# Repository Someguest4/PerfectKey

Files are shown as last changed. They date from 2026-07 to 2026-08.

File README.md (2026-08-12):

# Perfectionist Keyboard
A project following the [HackClub KEEB project tutorial](https://keeb.hackclub.com/docs), making a custom mechanical keyboard from scratch.

I have always been a perfectionist and I often find myself following the lines between the keys on my keyboard instead of doing my homework so I decided to make a keyboard with perfectly aligned keys.

## What it is
An ortholinear TKL keyboard, designed from scratch in KiCad. All modifier keys are 2u, spacebar is 7u, board is 380x147fmm with a strip for the Pico, switches are on the normal 19.05mm grid, USB-C with a cutout in the case, just one stabilizer for the spacebar, because the footprints wouldn't fit directly above each other and it's not like the 2u keys will wobble enough to need a stabilizer :|

## Repo structure
- `kicad/` - schematic and PCB layout, Gerbers, drill files
- `case/` - case and plate files
- `photos/` - build photos for journal
- `firmware/` compiled ready to flash firmware
## Build log

**2026-07-11 - Schematic:**
Read through the guide and designed the schematic. Switch matrix, diodes so it doesn't ghost, stabs, wired it all to the Pico.

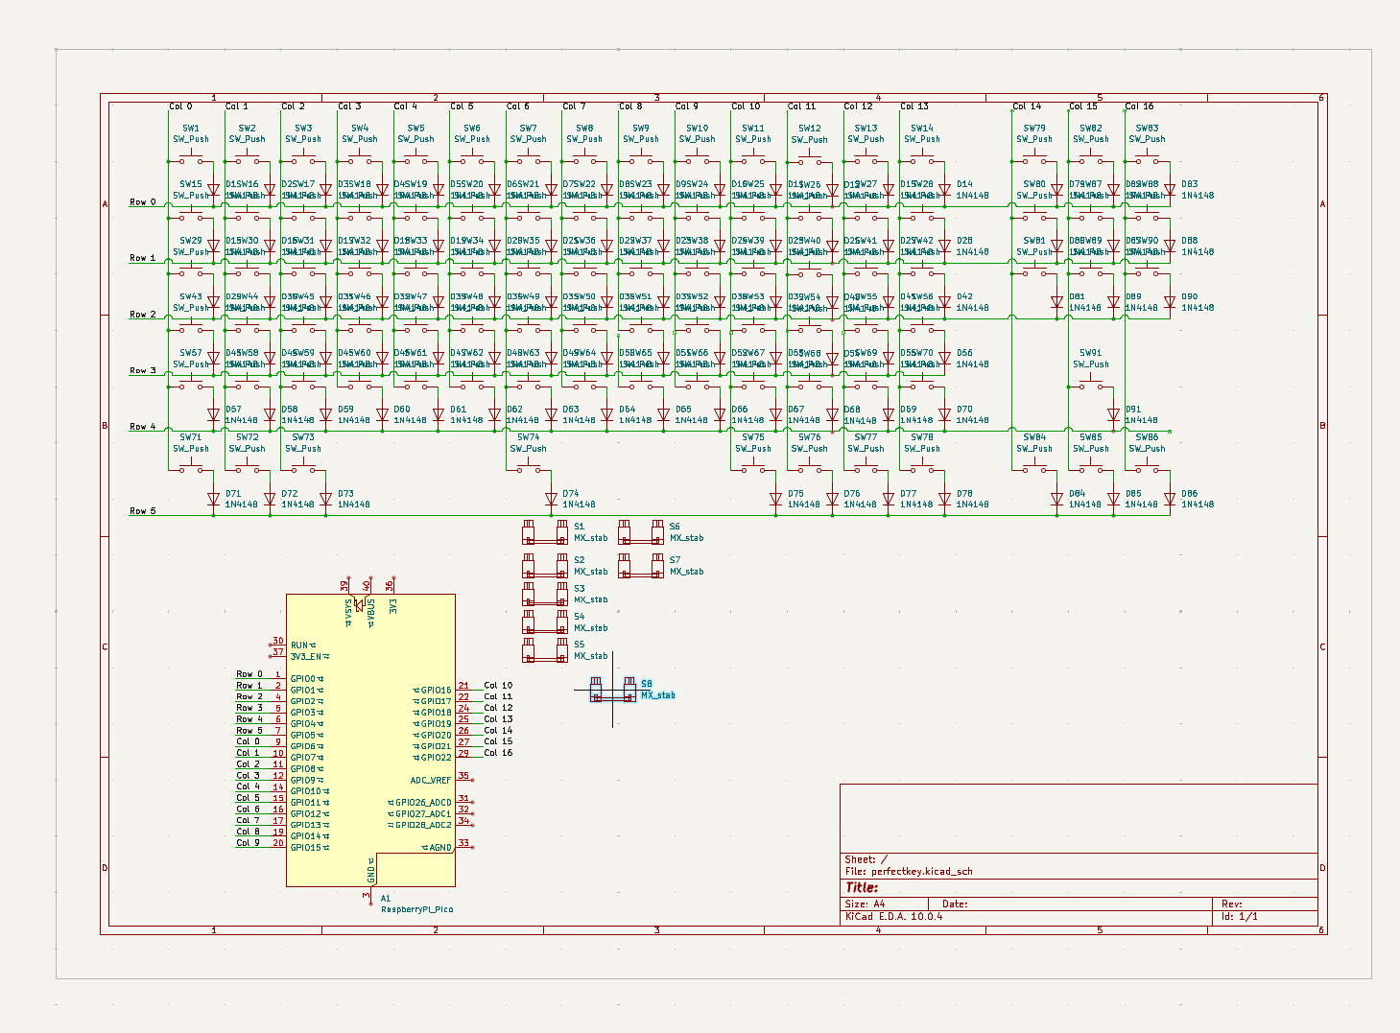
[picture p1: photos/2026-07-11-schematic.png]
Schematic


**2026-07-14 - Started placing switches:**

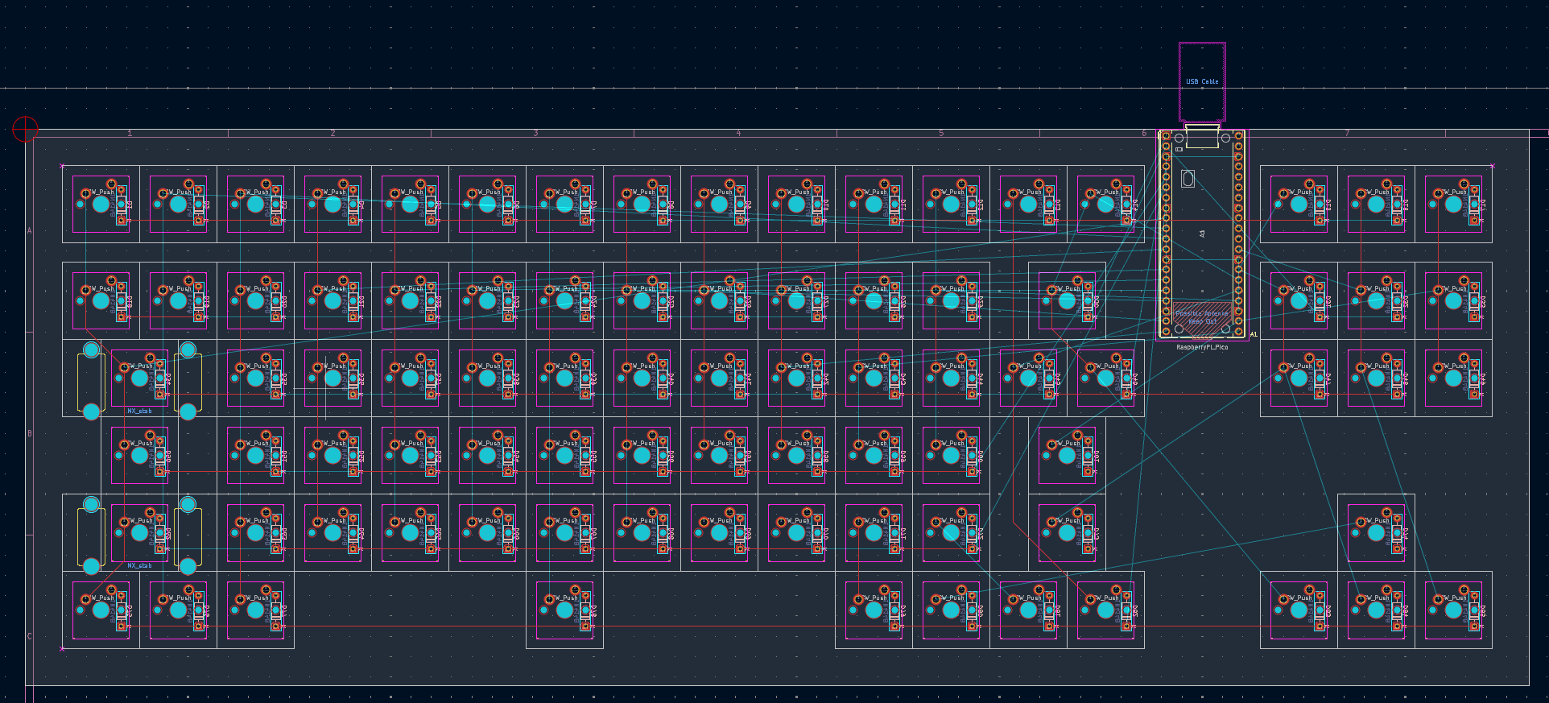
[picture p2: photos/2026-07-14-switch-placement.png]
Switch placement


**2026-07-15 - Switches were completely wrong:**
Got the kicad-kbplacer plugin to place the keys instead and made the layout in KLE.

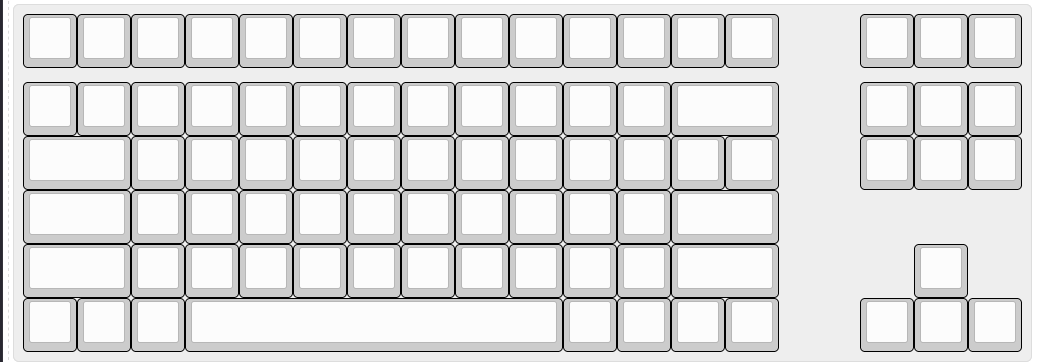
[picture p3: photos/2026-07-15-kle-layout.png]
KLE layout


**2026-07-16 - Numbering everything:**
Had to number all the keys in KLE because kbplacer wouldn't place them correctly without an index, renamed all the rows and columns so it would recognize them.
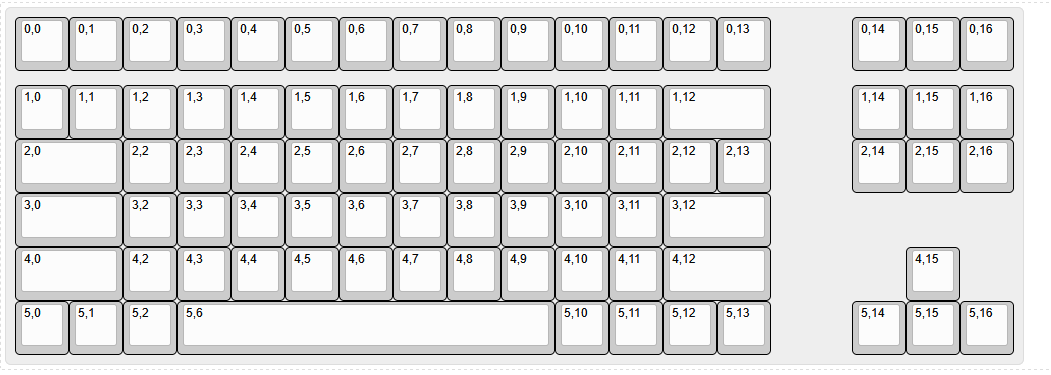
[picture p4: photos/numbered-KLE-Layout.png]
KLE layout


**2026-07-17 - Routing:**
Routing cables and rerouting until they fit.

**2026-07-18 - Diodes, PCB finished:**
Kbplacer put the diodes inside the courtyards of the switches and the cables were so tight around them. I couldn't move them, so I had to reroute first. PCB finished after that.

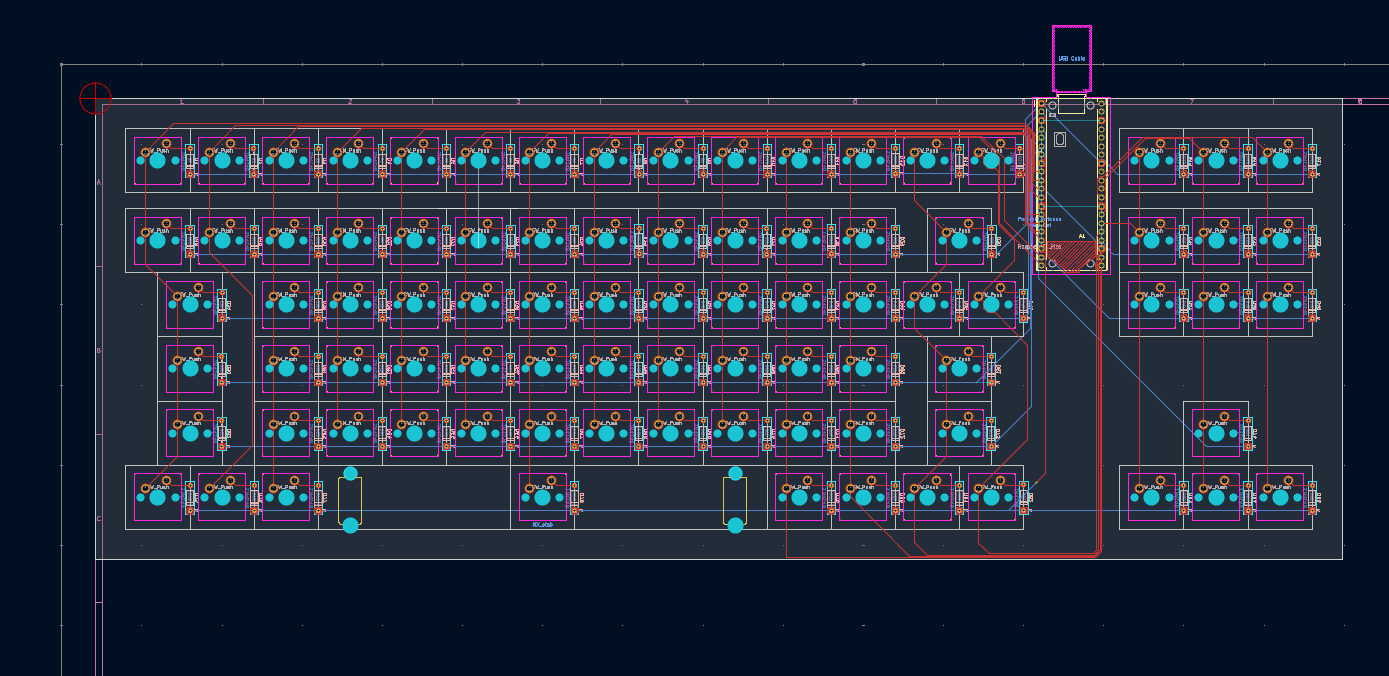
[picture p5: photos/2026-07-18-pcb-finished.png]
Finished PCB


**2026-07-22 - Starting the case:**
Started designing the case, rage quit because of Onshape (can't expect much from browser based software), switched to Fusion.

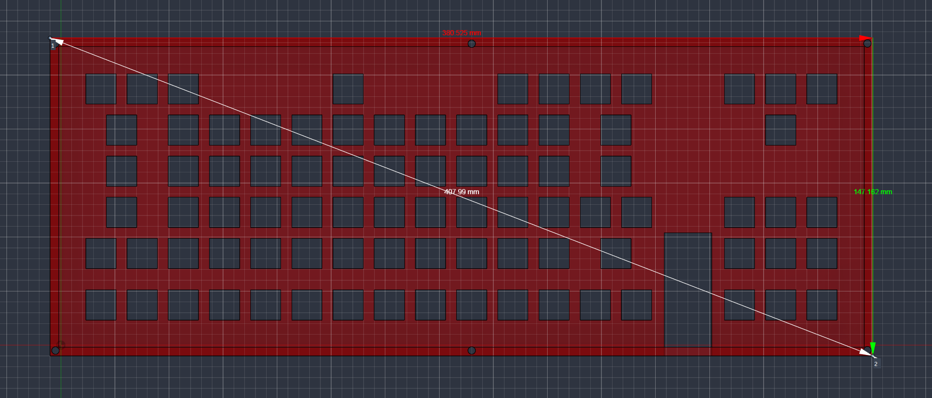
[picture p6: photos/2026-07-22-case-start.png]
Case start


**2026-07-23 - Case, mostly finished:**
Did most of the case but no space for screw holes.

**2026-07-24 - Case finished:**
Made the case bigger so the holes fit and made the top plate removable.

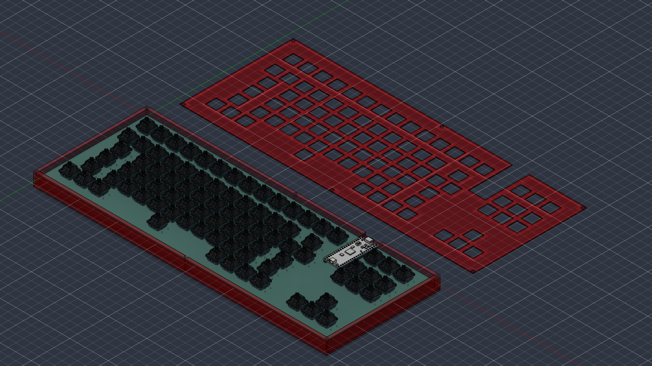
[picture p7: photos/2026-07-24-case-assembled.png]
Case assembled

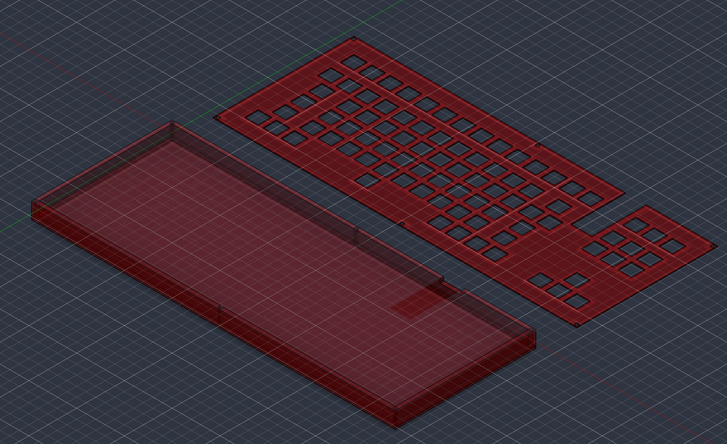
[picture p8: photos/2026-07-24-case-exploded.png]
Case exploded view


## Firmware
I went with QMK since I used it for my hackpad. All handwired since it's a custom layout. Compiles clean, just waiting on the actual hardware to test.

## Status
Everything done, hoping and waiting for approval

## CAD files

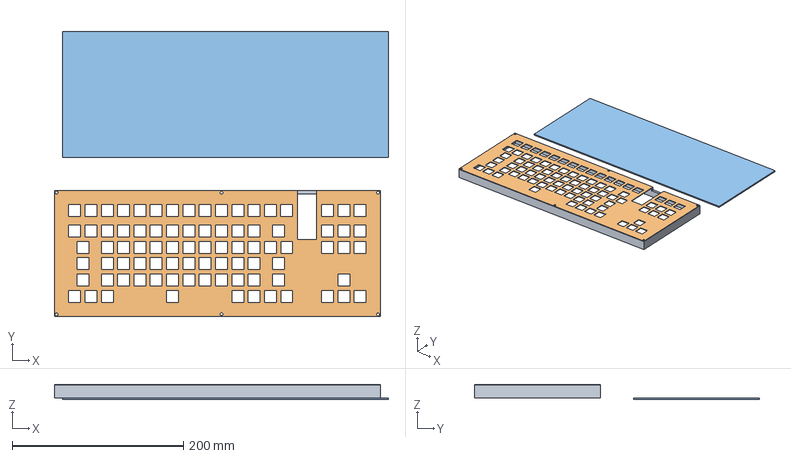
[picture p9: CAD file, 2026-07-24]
case/perfectkey_case.step
390.1 x 332.9 x 18.0 mm

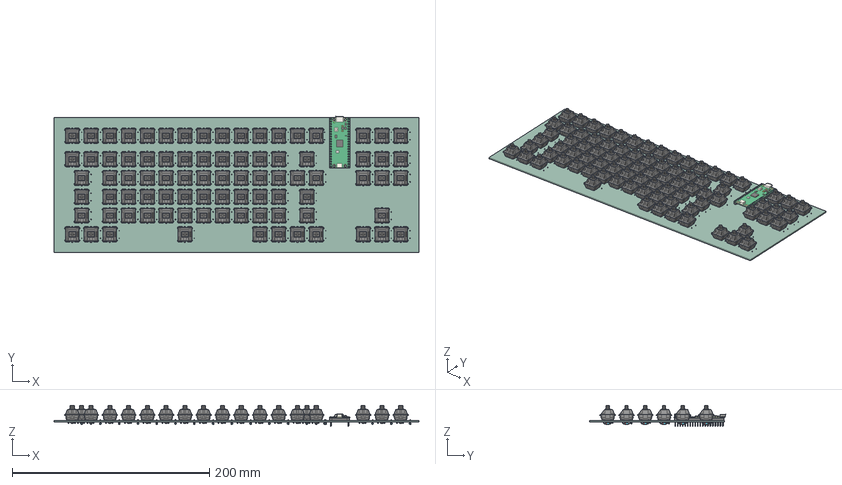
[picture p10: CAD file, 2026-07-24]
kicad/perfectkey_pcb.step
370.5 x 138.2 x 21.6 mm
MX1A-11NN x 85
RaspberryPi_Pico_H_Module_KiCad
RaspberryPi_Pico_Header_DIP-40_H2.54mm_KiCad
D_DO-35_SOD27_P7.62mm_Horizontal x 85
perfectkey_PCB

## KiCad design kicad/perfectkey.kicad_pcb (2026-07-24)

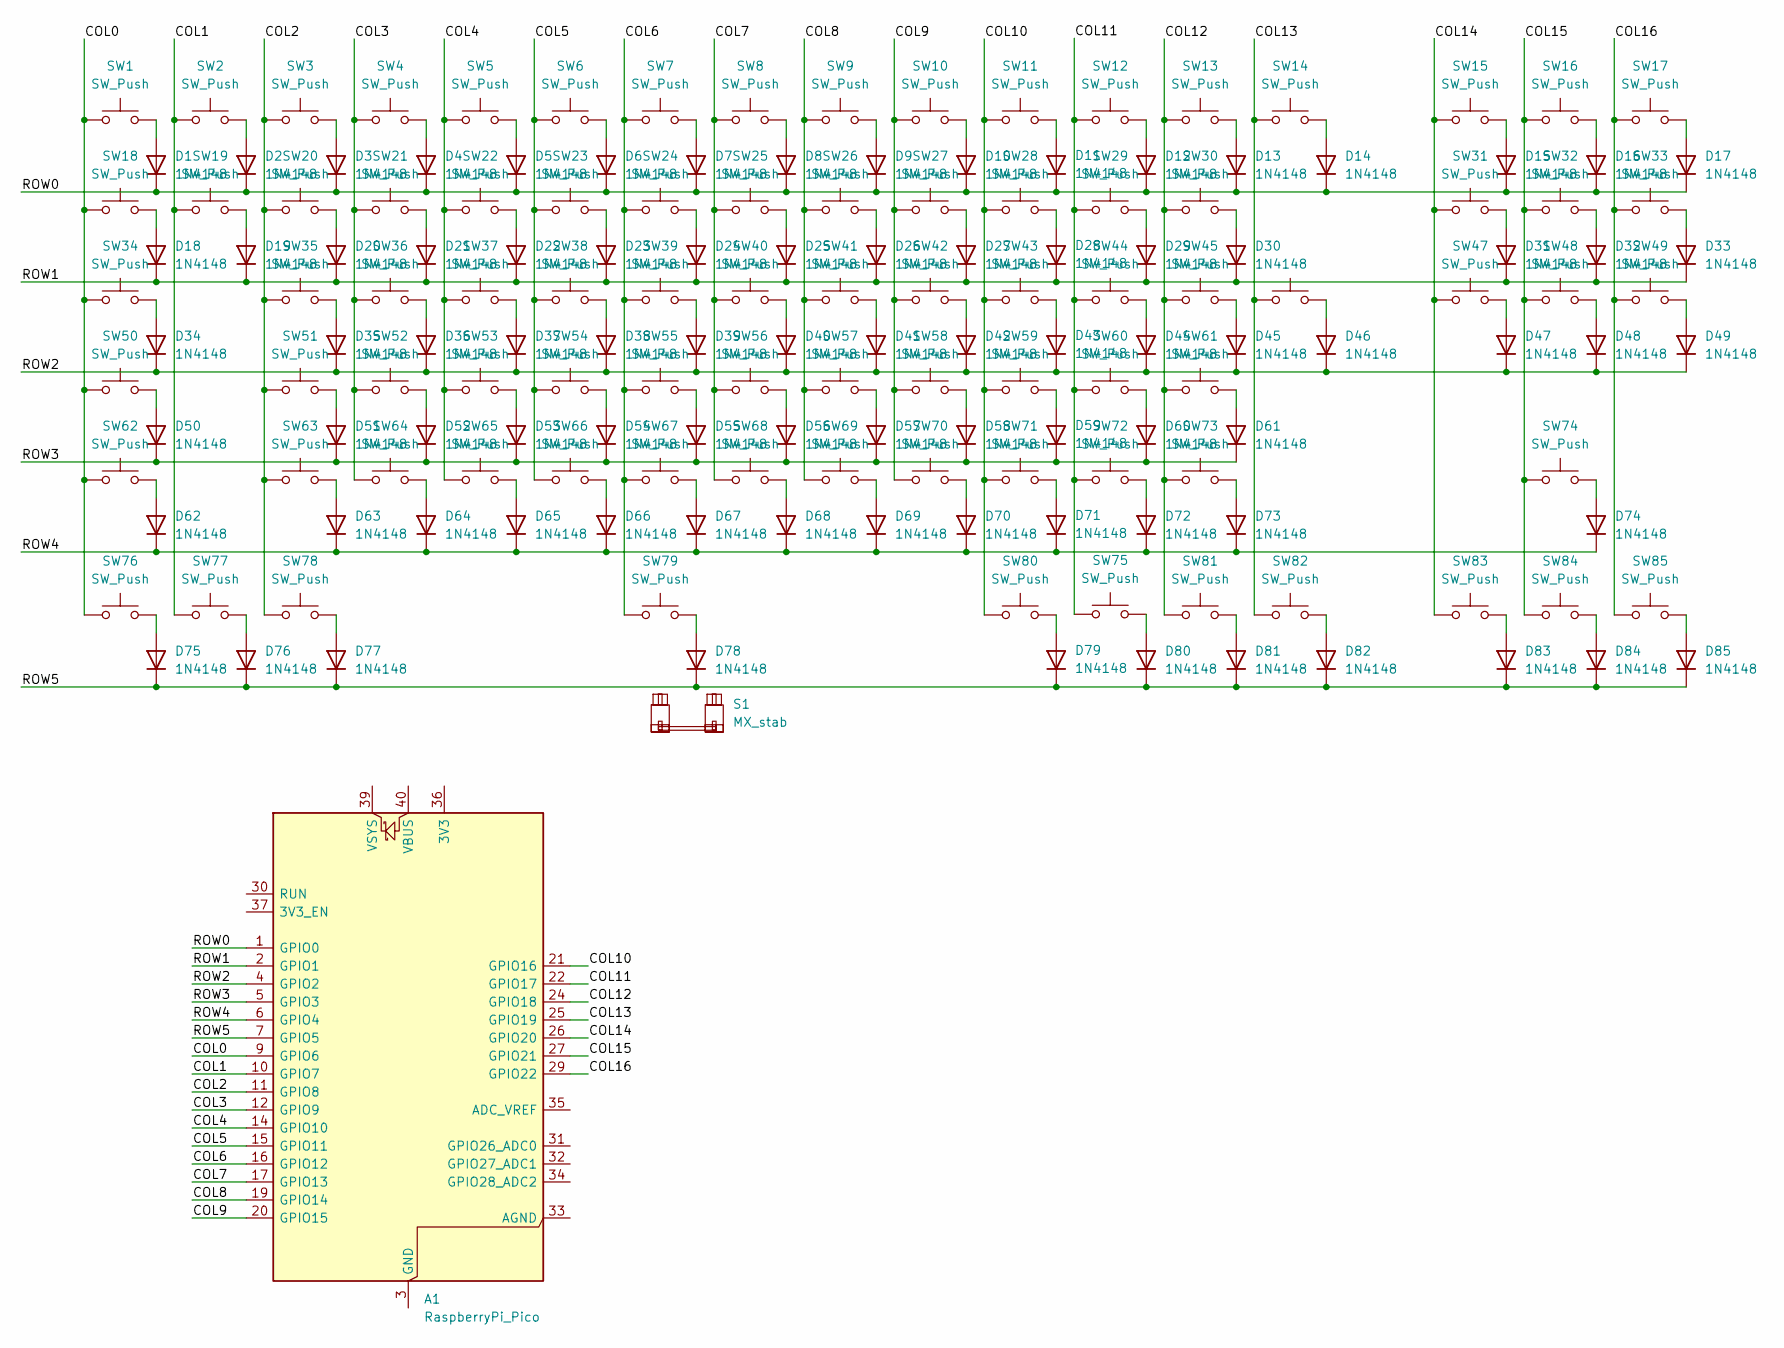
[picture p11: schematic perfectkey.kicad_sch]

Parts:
A1: RaspberryPi_Pico; RaspberryPi_Pico_Common_THT
D1, D2, D3, D4, D5, D6, D7, D8, D9, D10, D11, D12, D13, D14, D15, D16, D17, D18, D19, D20, D21, D22, D23, D24, D25, D26, D27, D28, D29, D30, D31, D32, D33, D34, D35, D36, D37, D38, D39, D40, D41, D42, D43, D44, D45, D46, D47, D48, D49, D50, D51, D52, D53, D54, D55, D56, D57, D58, D59, D60, D61, D62, D63, D64, D65, D66, D67, D68, D69, D70, D71, D72, D73, D74, D75, D76, D77, D78, D79, D80, D81, D82, D83, D84, D85: 1N4148; D_DO-35_SOD27_P7.62mm_Horizontal
S1: MX_stab; STAB_MX_7u
SW1, SW2, SW3, SW4, SW5, SW6, SW7, SW8, SW9, SW10, SW11, SW12, SW13, SW14, SW15, SW16, SW17, SW18, SW19, SW20, SW21, SW22, SW23, SW24, SW25, SW26, SW27, SW28, SW29, SW30, SW31, SW32, SW33, SW34, SW35, SW36, SW37, SW38, SW39, SW40, SW41, SW42, SW43, SW44, SW45, SW46, SW47, SW48, SW49, SW50, SW51, SW52, SW53, SW54, SW55, SW56, SW57, SW58, SW59, SW60, SW61, SW62, SW63, SW64, SW65, SW66, SW67, SW68, SW69, SW70, SW71, SW72, SW73, SW74, SW75, SW76, SW77, SW78, SW79, SW80, SW81, SW82, SW83, SW84, SW85: SW_Push; SW_MX_1u

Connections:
/COL0: A1.9 (GPIO6), SW1.1, SW18.1, SW34.1, SW50.1, SW62.1, SW76.1
/COL1: A1.10 (GPIO7), SW2.1, SW19.1, SW77.1
/COL2: A1.11 (GPIO8), SW3.1, SW20.1, SW35.1, SW51.1, SW63.1, SW78.1
/COL3: A1.12 (GPIO9), SW4.1, SW21.1, SW36.1, SW52.1, SW64.1
/COL4: A1.14 (GPIO10), SW5.1, SW22.1, SW37.1, SW53.1, SW65.1
/COL5: A1.15 (GPIO11), SW6.1, SW23.1, SW38.1, SW54.1, SW66.1
/COL6: A1.16 (GPIO12), SW7.1, SW24.1, SW39.1, SW55.1, SW67.1, SW79.1
/COL7: A1.17 (GPIO13), SW8.1, SW25.1, SW40.1, SW56.1, SW68.1
/COL8: A1.19 (GPIO14), SW9.1, SW26.1, SW41.1, SW57.1, SW69.1
/COL9: A1.20 (GPIO15), SW10.1, SW27.1, SW42.1, SW58.1, SW70.1
/COL10: A1.21 (GPIO16), SW11.1, SW28.1, SW43.1, SW59.1, SW71.1, SW80.1
/COL11: A1.22 (GPIO17), SW12.1, SW29.1, SW44.1, SW60.1, SW72.1, SW75.1
/COL12: A1.24 (GPIO18), SW13.1, SW30.1, SW45.1, SW61.1, SW73.1, SW81.1
/COL13: A1.25 (GPIO19), SW14.1, SW46.1, SW82.1
/COL14: A1.26 (GPIO20), SW15.1, SW31.1, SW47.1, SW83.1
/COL15: A1.27 (GPIO21), SW16.1, SW32.1, SW48.1, SW74.1, SW84.1
/COL16: A1.29 (GPIO22), SW17.1, SW33.1, SW49.1, SW85.1
/ROW0: A1.1 (GPIO0), D1.1 (K), D2.1 (K), D3.1 (K), D4.1 (K), D5.1 (K), D6.1 (K), D7.1 (K), D8.1 (K), D9.1 (K), D10.1 (K), D11.1 (K), D12.1 (K), D13.1 (K), D14.1 (K), D15.1 (K), D16.1 (K), D17.1 (K)
/ROW1: A1.2 (GPIO1), D18.1 (K), D19.1 (K), D20.1 (K), D21.1 (K), D22.1 (K), D23.1 (K), D24.1 (K), D25.1 (K), D26.1 (K), D27.1 (K), D28.1 (K), D29.1 (K), D30.1 (K), D31.1 (K), D32.1 (K), D33.1 (K)
/ROW2: A1.4 (GPIO2), D34.1 (K), D35.1 (K), D36.1 (K), D37.1 (K), D38.1 (K), D39.1 (K), D40.1 (K), D41.1 (K), D42.1 (K), D43.1 (K), D44.1 (K), D45.1 (K), D46.1 (K), D47.1 (K), D48.1 (K), D49.1 (K)
/ROW3: A1.5 (GPIO3), D50.1 (K), D51.1 (K), D52.1 (K), D53.1 (K), D54.1 (K), D55.1 (K), D56.1 (K), D57.1 (K), D58.1 (K), D59.1 (K), D60.1 (K), D61.1 (K)
/ROW4: A1.6 (GPIO4), D62.1 (K), D63.1 (K), D64.1 (K), D65.1 (K), D66.1 (K), D67.1 (K), D68.1 (K), D69.1 (K), D70.1 (K), D71.1 (K), D72.1 (K), D73.1 (K), D74.1 (K)
/ROW5: A1.7 (GPIO5), D75.1 (K), D76.1 (K), D77.1 (K), D78.1 (K), D79.1 (K), D80.1 (K), D81.1 (K), D82.1 (K), D83.1 (K), D84.1 (K), D85.1 (K)
unnamed: A1.3 (GND), A1.8 (GND), A1.13 (GND), A1.18 (GND), A1.23 (GND), A1.28 (GND), A1.38 (GND)
unnamed: D1.2 (A), SW1.2
unnamed: D2.2 (A), SW2.2
unnamed: D3.2 (A), SW3.2
unnamed: D4.2 (A), SW4.2
unnamed: D5.2 (A), SW5.2
unnamed: D6.2 (A), SW6.2
unnamed: D7.2 (A), SW7.2
unnamed: D8.2 (A), SW8.2
unnamed: D9.2 (A), SW9.2
unnamed: D10.2 (A), SW10.2
unnamed: D11.2 (A), SW11.2
unnamed: D12.2 (A), SW12.2
unnamed: D13.2 (A), SW13.2
unnamed: D14.2 (A), SW14.2
unnamed: D15.2 (A), SW15.2
unnamed: D16.2 (A), SW16.2
unnamed: D17.2 (A), SW17.2
unnamed: D18.2 (A), SW18.2
unnamed: D19.2 (A), SW19.2
unnamed: D20.2 (A), SW20.2
unnamed: D21.2 (A), SW21.2
unnamed: D22.2 (A), SW22.2
unnamed: D23.2 (A), SW23.2
unnamed: D24.2 (A), SW24.2
unnamed: D25.2 (A), SW25.2
unnamed: D26.2 (A), SW26.2
unnamed: D27.2 (A), SW27.2
unnamed: D28.2 (A), SW28.2
unnamed: D29.2 (A), SW29.2
unnamed: D30.2 (A), SW30.2
unnamed: D31.2 (A), SW31.2
unnamed: D32.2 (A), SW32.2
unnamed: D33.2 (A), SW33.2
unnamed: D34.2 (A), SW34.2
unnamed: D35.2 (A), SW35.2
unnamed: D36.2 (A), SW36.2
unnamed: D37.2 (A), SW37.2
unnamed: D38.2 (A), SW38.2
unnamed: D39.2 (A), SW39.2
unnamed: D40.2 (A), SW40.2
unnamed: D41.2 (A), SW41.2
unnamed: D42.2 (A), SW42.2
unnamed: D43.2 (A), SW43.2
unnamed: D44.2 (A), SW44.2
unnamed: D45.2 (A), SW45.2
unnamed: D46.2 (A), SW46.2
unnamed: D47.2 (A), SW47.2
unnamed: D48.2 (A), SW48.2
unnamed: D49.2 (A), SW49.2
unnamed: D50.2 (A), SW50.2
unnamed: D51.2 (A), SW51.2
unnamed: D52.2 (A), SW52.2
unnamed: D53.2 (A), SW53.2
unnamed: D54.2 (A), SW54.2
unnamed: D55.2 (A), SW55.2
unnamed: D56.2 (A), SW56.2
unnamed: D57.2 (A), SW57.2
unnamed: D58.2 (A), SW58.2
unnamed: D59.2 (A), SW59.2
unnamed: D60.2 (A), SW60.2
unnamed: D61.2 (A), SW61.2
unnamed: D62.2 (A), SW62.2
unnamed: D63.2 (A), SW63.2
unnamed: D64.2 (A), SW64.2
unnamed: D65.2 (A), SW65.2
unnamed: D66.2 (A), SW66.2
unnamed: D67.2 (A), SW67.2
unnamed: D68.2 (A), SW68.2
unnamed: D69.2 (A), SW69.2
unnamed: D70.2 (A), SW70.2
unnamed: D71.2 (A), SW71.2
unnamed: D72.2 (A), SW72.2
unnamed: D73.2 (A), SW73.2
unnamed: D74.2 (A), SW74.2
unnamed: D75.2 (A), SW76.2
unnamed: D76.2 (A), SW77.2
unnamed: D77.2 (A), SW78.2
unnamed: D78.2 (A), SW79.2
unnamed: D79.2 (A), SW80.2
unnamed: D80.2 (A), SW75.2
unnamed: D81.2 (A), SW81.2
unnamed: D82.2 (A), SW82.2
unnamed: D83.2 (A), SW83.2
unnamed: D84.2 (A), SW84.2
unnamed: D85.2 (A), SW85.2

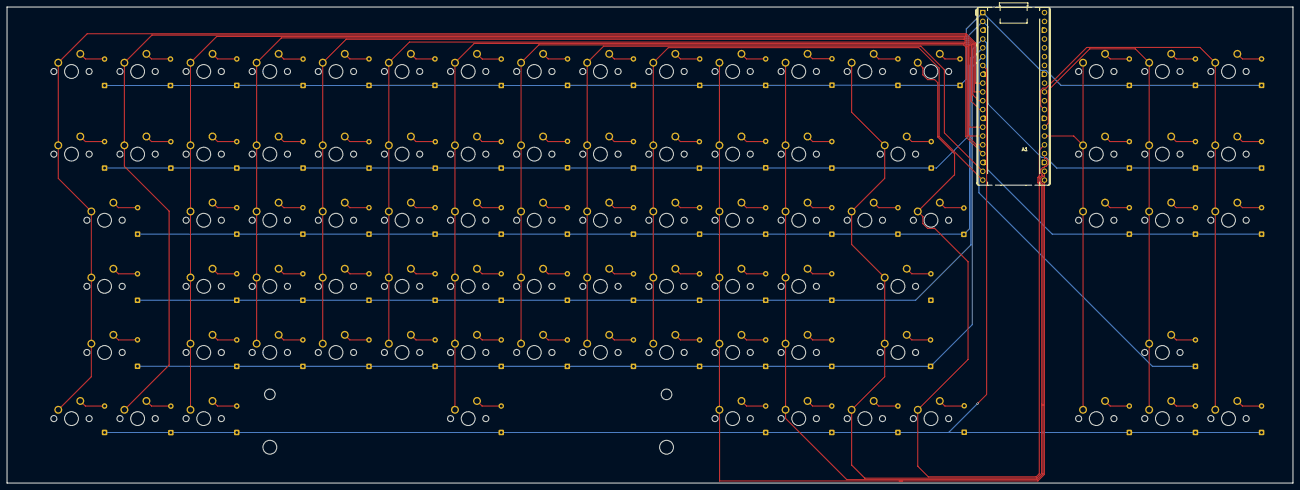
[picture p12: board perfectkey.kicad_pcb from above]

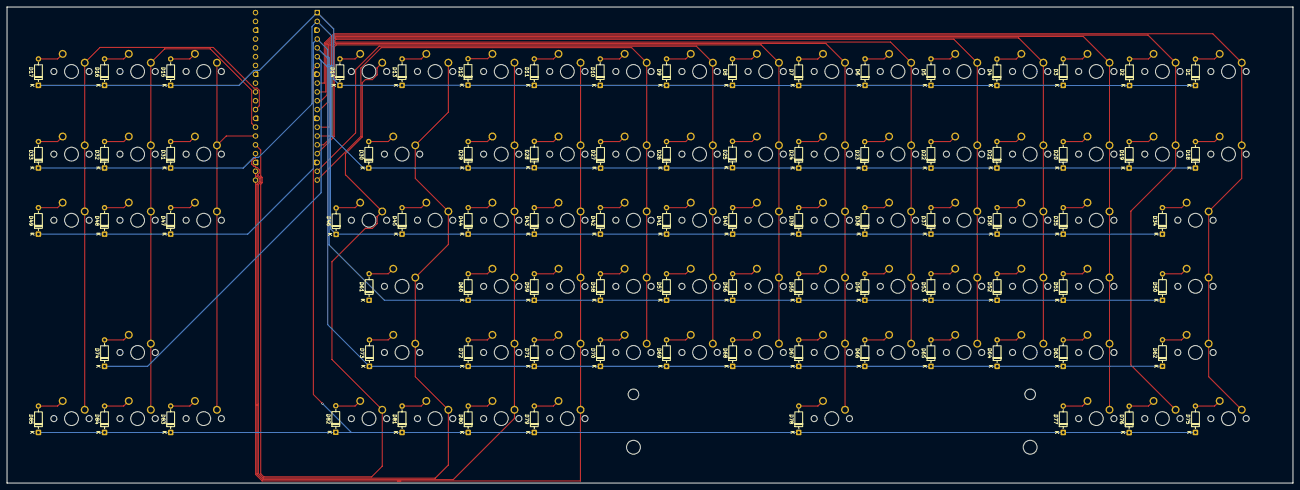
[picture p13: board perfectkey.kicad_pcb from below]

Board: 2 copper layers, 370.5 x 137.2 mm, 172 parts (85 on the bottom side), 109 nets.

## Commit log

2026-07-24 Designed PCB and case
    [perfectkey.kicad_pcb, perfectkey.kicad_sch, perfectkey_case.step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]
2026-07-24 Added pictures for the journal and updated schematic and pcb to have only 1 stabilizer for the spacebar
    [perfectkey.kicad_pcb, perfectkey.kicad_sch]
2026-08-12 Update README with case design progress
2026-08-12 updated case dimensions in readme
2026-08-12 updated case size in readme
